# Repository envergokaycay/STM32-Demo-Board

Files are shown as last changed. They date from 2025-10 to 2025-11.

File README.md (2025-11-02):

# 🧠 STM32F417 Demo Board

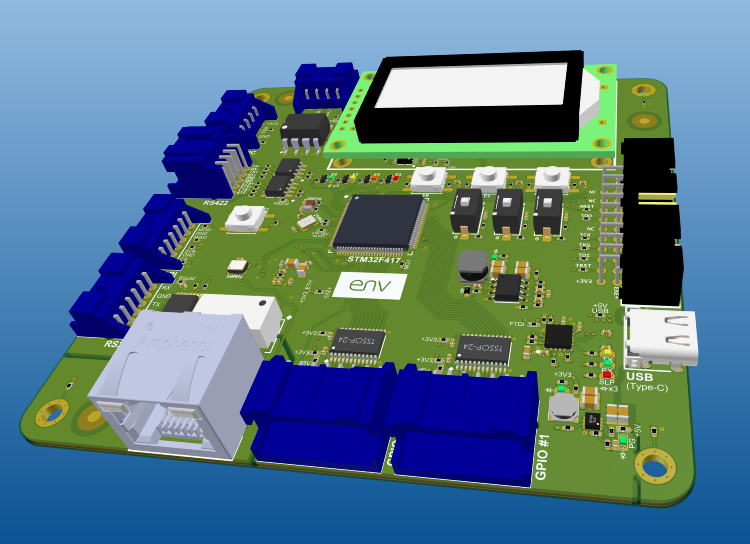
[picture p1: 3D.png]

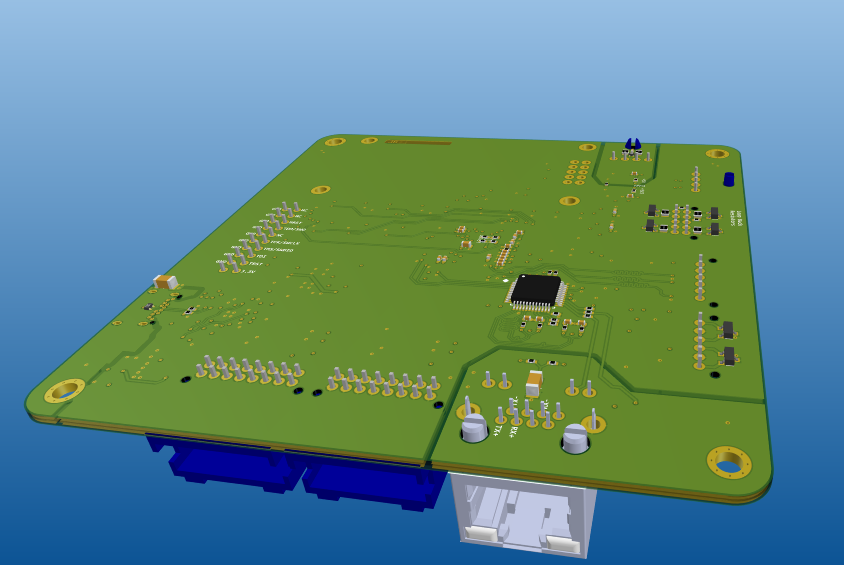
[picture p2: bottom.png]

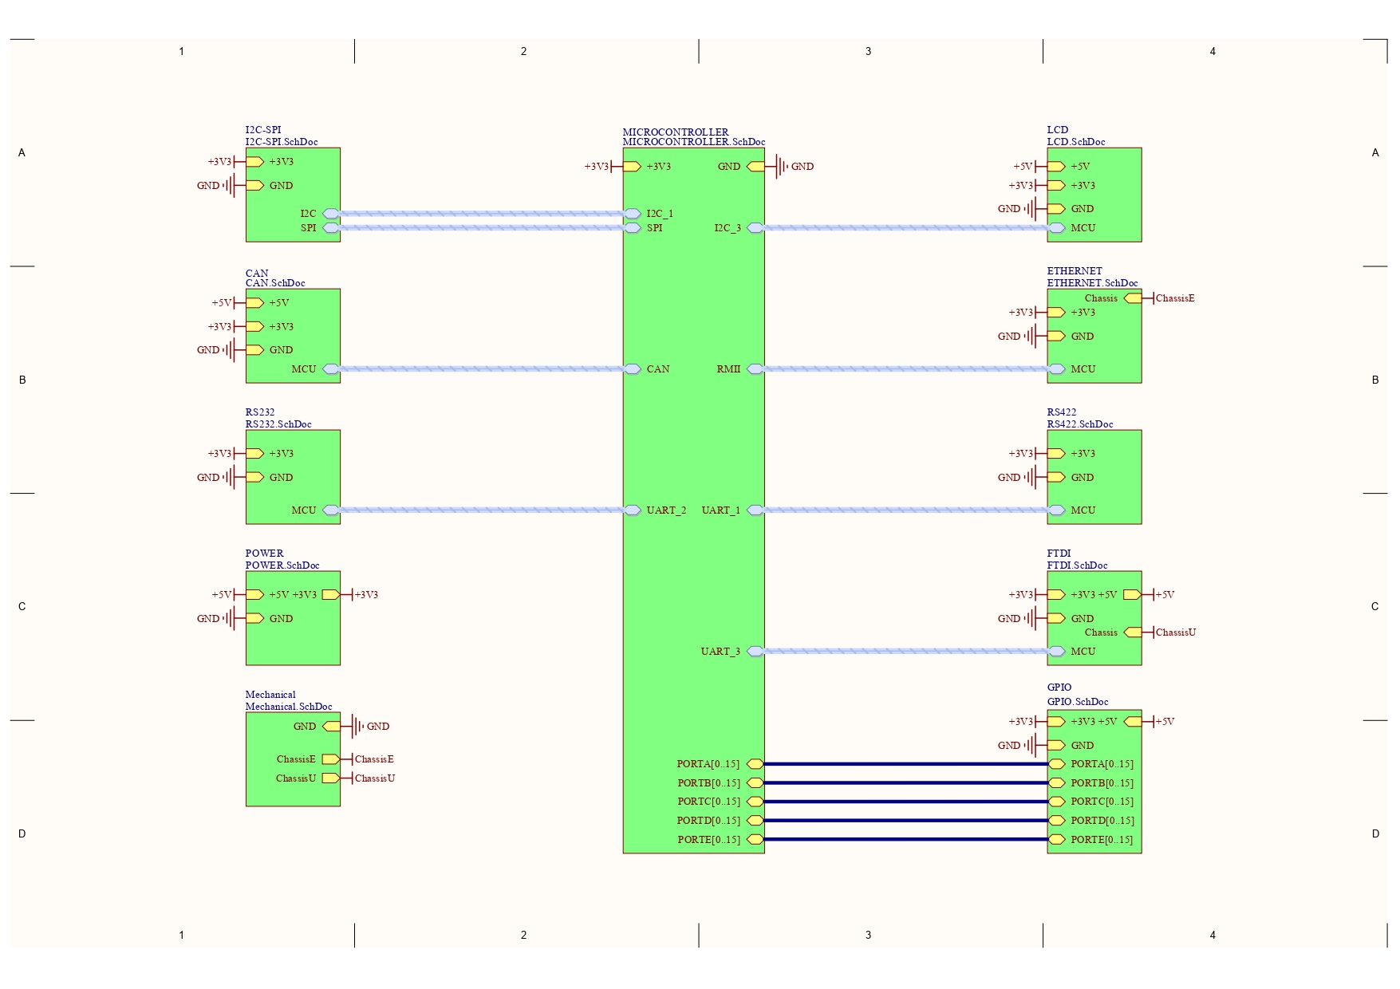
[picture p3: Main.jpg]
Main Board View


## 📘 Project Overview
This project presents a **multi-purpose demo board** developed for embedded system applications based on the **STM32F417VGT6** microcontroller.  
The design integrates communication, power management, and peripheral systems into a single modular platform suitable for both **educational** and **R&D** purposes.

---

## ⚙️ Technical Specifications

### 🔌 Power Management
- Input Voltage: **+5V / +3.3V regulation**
- Power Regulators: **AP3441SHE-7B, RT2862GSP**
- Power lines are monitorable via **LED indicators**

### 🧩 Microcontroller
- **STM32F417VGT6** (ARM Cortex-M4, 168 MHz, 1 MB Flash, 192 KB RAM)
- All **GPIO ports (A–E)** are accessible through pin headers.
- Includes **25 MHz external crystal oscillator** and **32.768 kHz RTC crystal**

### 🔄 Communication Interfaces
- **RS232** – Full UART conversion with TRS3232IPWR driver  
- **RS422** – Differential communication via SN65HVD30D transceiver  
- **CAN** – Industrial-level communication using ISO1050DUBR isolated driver  
- **USB-UART (FTDI)** – Implemented with FT230XQ-R chip for programming and serial communication  
- **Ethernet** – DP83848IVV/NOPB PHY over RMII protocol with RJ45 connector  

### 🖥️ Display Interface
- **I2C-based 8x2 LCD** (AMC0802BR)
- Level shifter: **NVT2002DP**
- Supports **backlight control** and **contrast adjustment**

### 🔬 Other Components
- **TVS diode protection** for all communication ports  
- **SWD/JTAG** programming interface  
- **Reset and Boot** push buttons  
- **GPIO expansion headers**

---

## 🧱 Hardware Files
The project was designed using **Altium Designer 23+**.  
It includes the following schematic files:

- `POWER.SchDoc` – Power circuit  
- `MICROCONTROLLER.SchDoc` – STM32F417 core  
- `CAN.SchDoc`, `RS232.SchDoc`, `RS422.SchDoc` – Communication modules  
- `FTDI.SchDoc` – USB–UART interface  
- `LCD.SchDoc` – Display module  
- `ETHERNET.SchDoc` – RMII Ethernet subsystem  
- `GPIO.SchDoc` – Pin mapping and expansion  
- `Mechanical.SchDoc` – Mechanical dimensions and references  

---

## 🧰 Development Environment
- **EDA Software:** Altium Designer 23.0  
- **Microcontroller IDE:** STM32CubeIDE  
- **Programming Interface:** ST-Link V2  
- **PCB Layers:** 4-layer  
- **Power Planes:** +3.3V / +5V / GND separated  

---

## 🚀 Use Cases
- Embedded system test platform  
- RS232/RS422/CAN communication experiments  
- Ethernet-based IoT or data transfer projects  
- LCD-based menu interface prototyping  
- Educational and hardware verification environments  

---

## 📁 Project Structure
```
📂 STM32F417_Demo_Board
 ├── Schematic_Files/
 │   ├── POWER.SchDoc
 │   ├── MICROCONTROLLER.SchDoc
 │   ├── RS232.SchDoc
 │   ├── RS422.SchDoc
 │   ├── CAN.SchDoc
 │   ├── LCD.SchDoc
 │   ├── FTDI.SchDoc
 │   ├── ETHERNET.SchDoc
 │   └── GPIO.SchDoc
 ├── PCB/
 │   └── STM32F417_Demo_Board.PcbDoc
 ├── Outputs/
 │   ├── Gerber/
 │   ├── Assembly/
 │   └── PDF/
 └── README.md
```

---

## 👨‍💻 Contact
If you have any questions or want to collaborate, feel free to reach out via GitHub or [LinkedIn](https://www.linkedin.com/in/envergokaycay/).

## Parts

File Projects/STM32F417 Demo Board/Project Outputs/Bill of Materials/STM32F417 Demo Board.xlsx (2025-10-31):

Description | Manufacturer | Manufacturer Part Number | Supplier Part Number | Supplier | Quantity | Supplier Currency | Supplier Link | Price, Min | Price, Max | Quantity, Min | Quantity, Max
 | KYOCERA AVX | 04026D104KAT4A | 478-11504-1-ND | Digikey | 47 | $ | https://www.digikey.com/en/products/detail/kyocera-avx/04026D104KAT4A/8107673 | $0.08000 | $0.00240 | 1 | 50,000
Cap, Cer, 22uF, 6.3V, M2012 | Murata | GRM21BR60J226ME39K | 490-6471-1-ND | Digikey | 8 | $ | https://www.digikey.com/en/products/detail/murata-electronics/GRM21BR60J226ME39K/2546881 | $0.21000 | $0.02815 | 1 | 30,000
Cap, Cer, 22pF, 25V, M1005 | Walsin | 0402N220J250CT | 1292-1282-1-ND | Digikey | 7 | $ | https://www.digikey.com/en/products/detail/walsin-technology-corporation/0402N220J250CT/9354779 | $0.10000 | $0.00128 | 1 | 250,000
Cap, Cer, 2.7nF, 50V, M1005 | Yageo | CC0402KRX7R9BB272 | 311-1033-1-ND | Digikey | 1 | $ | https://www.digikey.com/en/products/detail/yageo/CC0402KRX7R9BB272/302767 | $0.10000 | $0.00128 | 1 | 250,000
Cap, Cer, 1uF, 6.3V, M1005 | Samsung | CL10A475KQ8NNNC | 1276-1045-1-ND | Digikey | 2 | $ | https://www.digikey.com/en/products/detail/samsung-electro-mechanics/CL10A475KQ8NNNC/3886703 | $0.08000 | $0.00431 | 1 | 4,000
Cap, Cer, 1nF, 2kV, M3216 | Yageo | CC1206MKX7RDBB102 | 311-4501-1-ND | Digikey | 3 | $ | https://www.digikey.com/en/products/detail/yageo/CC1206MKX7RDBB102/5884663 | $0.23000 | $0.03901 | 1 | 75,000
Cap, Cer, 1uF, 6.3V, M1005 | Samsung | CL05A105MQ5NNNC | 1276-1235-1-ND | Digikey | 2 | $ | https://www.digikey.com/en/products/detail/samsung-electro-mechanics/CL05A105MQ5NNNC/3886893 | $0.10000 | $0.00211 | 1 | 250,000
Cap, Cer, 16pF, 50V, M1005 | Walsin | 0402N160J500CT | 1292-1262-1-ND | Digikey | 2 | $ | https://www.digikey.com/en/products/detail/walsin-technology-corporation/0402N160J500CT/9354759 | $0.10000 | $0.00182 | 1 | 250,000
Cap, Cer, 1uF, 6.3V, M1005 | Samsung | CL05A225MQ5NNNC | 1276-1469-1-ND | Digikey | 2 | $ | https://www.digikey.com/en/products/detail/samsung-electro-mechanics/CL05A225MQ5NNNC/3887127 | $0.08000 | $0.00241 | 1 | 10,000
Cap, Cer, 10uF, 6.3V, M2012 | Samsung | CL21A106MQFNNNE | 1292-1282-1-ND | Digikey | 2 | $ | https://www.digikey.com/en/products/detail/samsung-electro-mechanics/CL21A106MQFNNNE/3886956 | $0.10000 | $0.00846 | 1 | 50,000
Conn, JST, 4P, TH, XA, Side Entry | JST | S04B-XASK-1(LF)(SN) | 455-4090-ND | Digikey | 2 | $ | https://www.digikey.com/en/products/detail/jst-sales-america-inc/S04B-XASK-1-LF-SN/7230506 | $0.40000 | $0.21016 | 1 | 10,000
Connector, 6Pin | JST | S06B-PASK-2 | 455-S06B-PASK-2-ND | Digikey | 2 | $ | https://www.digikey.com/en/products/detail/jst-sales-america-inc/S06B-PASK-2/926757 | $0.38000 | $0.20057 | 1 | 10,000
Conn, JST, 16P, TH, PAD, Side Entry | JST | S16B-PADSS-1(LF)(SN) | 455-2037-ND | Digikey | 2 | $ | https://www.digikey.com/en/products/detail/jst-sales-america-inc/S16B-PADSS-1-LF-SN/1634778 | $0.62000 | $0.33258 | 1 | 10,080
Conn, JST, 10P, TH, PAD, Side Entry | JST | S10B-PADSS-1(LF)(SN) | 455-2032-ND | Digikey | 1 | $ | https://www.digikey.com/en/products/detail/jst-sales-america-inc/S10B-PADSS-1-LF-SN/1634773
Connector, USB, Type-C | GCT | USB4056-03-A | 2073-USB4056-03-ACT-ND | Digikey | 1 | $ | https://www.digikey.com/en/products/detail/gct/usb4056-03-a/14638038 | $0.91000 | $0.47490 | 1 | 10,000
Conn, Header, 20P, RA, TH, Shrouded | Omron | XG4C-2034 | OR900-ND | Digikey | 1 | $ | https://www.digikey.com/en/products/detail/omron-electronics-inc-emc-div/XG4C-2034/1787182 | 1.97 | 1.27716 | 1 | 450
RJ45 - Amphenol, RJHSE-x38-A1 | Amphenol | RJHSE-x38-A1 | RJHSE5381A1-ND | Digikey | 1 | $ | https://www.digikey.com/en/products/detail/amphenol-icc-commercial-products/rjhse5381a1/3083556 | $1.90000 | $1.09002 | 1 | 2,520
Diode, Schottky, 30V, 200mA, SOD-523 | Toshiba | CES521,L3F | CES521L3FCT-ND | Digikey | 1 | $ | https://www.digikey.com/en/products/detail/toshiba-semiconductor-and-storage/CES521-L3F/3522356 | $0.13000 | $0.01500 | 1 | 16,000
 | Rohm Semiconductor | SML-D12U1WT86 | SML-D12U1WT86CT-ND | Digikey | 11 | $ | https://www.digikey.com/en/products/detail/rohm-semiconductor/sml-d12u1wt86/5843853 | $0.12000 | $0.02318 | 1 | 300000
Diode, TVS, 5V/6.8V, SOD-723 | Toshiba | DF3A6.8LFV,L3F | DF3A6.8LFVL3FCT-ND | Digikey | 2 | $ | https://www.digikey.com/en/products/detail/toshiba-semiconductor-and-storage/DF3A6-8LFV-L3F/4305070 | $0.14000 | $0.02250 | 1 | 8,000
Housing, JST, 4P, XA | JST | XAP-04V-1 | 455-2150-ND | Digikey | 2 | $ | https://www.digikey.com/en/products/detail/jst-sales-america-inc/XAP-04V-1/959010 | $0.10000 | $0.05137 | 1 | 3,000
Housing, 6Pin | JST | PADP-16V-1-S | 455-2143-ND | Digikey | 2 | $ | https://www.digikey.com/en/products/detail/jst-sales-america-inc/PADP-16V-1-S/1300224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 | $0.26000 | $0.14985 | 1 | 3,000
Housing, 6Pin | JST | PADP-10V-1-S | 455-2140-ND | Digikey | 1 | $ | https://www.digikey.com/en/products/detail/jst-sales-america-inc/PADP-10V-1-S/1300221 | $0.13000 | $0.07648 | 1 | 3,000
Housing, 6Pin | JST | PAP-06V-S | 455-1490-ND | Digikey | 2 | $ | https://www.digikey.com/en/products/detail/jst-sales-america-inc/pap-06v-s/759978 | $0.13000 | $0.07648 | 1 | 3,000
IC, Power, DC-DC, Richtek, RT2862xSP | Richtek | RT2862GSP | 1028-1373-1-ND | Digikey | 1 | $ | https://www.digikey.com/en/products/detail/richtek-usa-inc/rt2862gsp/5880463 | $1.79000 | $0.87336 | 1 | 7,500
IC, Power, DC-DC, Diodes, AP3441 | Diodes | AP3441SHE-7B | AP3441SHE-7BDICT-ND | Digikey | 1 | $ | https://www.digikey.com/en/products/detail/diodes-incorporated/AP3441SHE-7B/9765636 | $0.31000 | $0.13728 | 1 | 1,000
IC, Buffer, Nexperia, TSSOP-24 | Nexperia | 74LVC4245APW,118 | 1727-4308-1-ND | Digikey | 2 | $ | https://www.digikey.com/en/products/detail/nexperia-usa-inc/74lvc4245apw-118/1231659 | $0.71000 | $0.34850 | 1 | 1,000
IC, Interface, CAN, DIP-8 | Texas Instruments | ISO1050DUBR | 296-24818-1-ND | Digikey | 1 | $ | https://www.digikey.com/en/products/detail/texas-instruments/iso1050dubr/2094633 | $3.72000 | $2.32380 | 1 | 100
IC, Interface, RS232, Texas | Texas Instruments | TRS3232IPWR | 296-25041-1-ND | Digikey | 1 | $ | https://www.digikey.com/en/products/detail/texas-instruments/trs3232ipwr/1909117 | $1.73000 | $0.90061 | 1 | 1,000
IC, Interface, RS422, Texas | Texas Instruments | SN65HVD30D | 296-26346-5-ND | Digikey | 2 | $ | https://www.digikey.com/en/products/detail/texas-instruments/sn65hvd30d/1574539
IC, Interface, I2C, TSSOP-8 | Nexperia | NVT2002DP,118 | 568-5121-1-ND | Digikey | 1 | $ | https://www.digikey.com/en/products/detail/nxp-usa-inc/NVT2002DP-118/2355938 | $0.62000 | $0.25914 | 1 | 25,000
Module, LCD, Orient, AMC0802BR-B-B6WTDW-SPI | Orient Display | AMC0802BR-B-B6WTDW-I2C | 5491-AMC0802BR-B-B6WTDW-I2C-ND | Digikey | 1 | $ | https://www.digikey.com/en/products/detail/orient-display/amc0802br-b-b6wtdw-i2c/22531884 | $10.32000 | $5.74189 | 1 | 1,000
IC, Interface, FTDI, QFN-16 | FTDI | FT230XQ-R | 768-1130-1-ND | Digikey | 1 | $ | https://www.digikey.com/en/products/detail/ftdi-future-technology-devices-international-ltd/FT230XQ-R/3029142 | $2.26000 | $1.63030 | 1 | 5,000
IC, MCU, STM32F417VxTx, QFP-100 | STM | STM32F417VGT6 | 497-11900-ND | Digikey | 1 | $ | https://www.digikey.com/en/products/detail/stmicroelectronics/stm32f417vgt6/2757684 | $12.09000 | $7.40087 | 1 | 1080
IC, Interface, Eth Phy, 10/100Mb, DP83848IVV | Texas | DP83848IVV/NOPB | DP83848IVV/NOPB-ND | Digikey | 1 | $ | https://www.digikey.com/en/products/detail/texas-instruments/DP83848IVV-NOPB/947543 | $6.93000 | $3.95780 | 1 | 2,500
IC, Oscillator, 50 MHz | ESC | ECS-2333-500-BN-TR | XC1930CT-ND | Digikey | 1 | $ | https://www.digikey.com/en/products/detail/ecs-inc/ecs-2333-500-bn-tr/3927356 | $0.90000 | $0.61814 | 1 | 500
Inductor | Taiyo Yuden | NRS5020T4R7MMGJ | 587-2890-1-ND | Digikey | 1 | $ | https://www.digikey.com/en/products/detail/taiyo-yuden/NRS5020T4R7MMGJ/2230192 | $0.18000 | $0.07087 | 1 | 87,750
Inductor | Taiyo Yuden | NRS4018T2R2MDGJ | 587-2890-1-ND | Digikey | 1 | $ | https://www.digikey.com/en/products/detail/taiyo-yuden/nrs4018t2r2mdgj/2648968 | $0.18000 | $0.07087 | 1 | 87,750
Logo |  |  |  |  | 1
Pin, JST, SXA-001T-P0.6 | JST | SXA-001T-P0.6 | 455-1904-1-ND | Digikey | 8 | $ | https://www.digikey.com/en/products/detail/jst-sales-america-inc/SXA-001T-P0-6/923775 | $0.01620 | $0.01171 | 8,000 | 800,000
Pin | JST | SPND-001T-C0.5 | 455-2303-1-ND | Digikey | 42 | $ | https://www.digikey.com/en/products/detail/jst-sales-america-inc/SPND-001T-C0-5/1788519 | $0.02410 | $* | 1,000
Pin | JST | SPHD-001T-P0.5 | 455-1325-1000-ND | Digikey | 12 | $ | https://www.digikey.com/en/products/detail/jst-sales-america-inc/sphd-001t-p0-5/26212452 | $0.02410 | $* | 1,000
MOSFET, N-CH, 20V, 100mA, SOT-416FL | Rohm | RE1C001UNTCL | RE1C001UNTCLCT-ND | Digikey | 4 | $ | https://www.digikey.com/en/products/detail/rohm-semiconductor/RE1C001UNTCL/4004557 | $0.30000 | $0.03713 | 1 | 15,000
Res, 1K, 1%, M1005 | Yageo | RC0402FR-071KP | YAG1254CT-ND | Digikey | 10 | $ | https://www.digikey.com/en/products/detail/yageo/RC0402FR-071KP/4935269 | $0.10000 | $0.00306 | 1 | 10,000
Res, 100K, 1%, M1005 | Yageo | RC0402FR-07100KP | 13-RC0402FR-07100KPCT-ND | Digikey | 11 | $ | https://www.digikey.com/en/products/detail/yageo/RC0402FR-07100KP/12698883 | $0.12000 | $0.00306 | 1 | 10,000
Res, 330R, 1%, M1005 | Yageo | RC0402FR-07330RL | 311-330LRCT-ND | Digikey | 20 | $ | https://www.digikey.com/en/products/detail/yageo/RC0402FR-07330RL/726594 | $0.10000 | $0.00181 | 1 | 250,000
 | Yageo | RC0402FR-070RL | 311-0.0LRCT-ND | Digikey | 39 | $ | https://www.digikey.com/en/products/detail/yageo/RC0402FR-070RL/2827570 | $0.10000 | $0.00133 | 1 | 250000
Res, 150K, 1%, M1005 | Yageo | RC0402FR-07150KL | 311-150KLRCT-ND | Digikey | 1 | $ | https://www.digikey.com/en/products/detail/yageo/RC0402FR-07150KL/726542 | $0.11000 | $0.00181 | 1 | 250,000
Res, 75K, 1%, M1005 | Yageo | RC0402FR-0775KL | 311-75KLRCT-ND | Digikey | 1 | $ | https://www.digikey.com/en/products/detail/yageo/RC0402FR-0775KL/2827576 | $0.10000 | $0.00181 | 1 | 250,000
Res, 24K, 1%, M1005 | Yageo | RC0402FR-0724KL | 311-24KLRCT-ND | Digikey | 1 | $ | https://www.digikey.com/en/products/detail/yageo/RC0402FR-0724KL/2827581 | $0.10000 | $0.00153 | 1 | 20,000
Res, 56K, 1%, M1005 | Yageo | RC0402FR-0756KL | 311-56.0KLRCT-ND | Digikey | 2 | $ | https://www.digikey.com/en/products/detail/yageo/RC0402FR-0756KL/726635 | $0.10000 | $0.00181 | 1 | 250,000
Res, 16K, 1%, M1005 | Yageo | RC0402FR-0716KL | 311-16.0KLRCT-ND | Digikey | 1 | $ | https://www.digikey.com/en/products/detail/yageo/RC0402FR-0716KL/726544 | $0.10000 | $0.00127 | 1 | 10,000
Res, 453K, 1%, M1005 | Yageo | RC0402FR-07453KL | YAG3164CT-ND | Digikey | 1 | $ | https://www.digikey.com/en/products/detail/yageo/RC0402FR-07453KL/5281024 | $0.10000 | $0.00127 | 1 | 10,000
Res, 2.2K, 1%, M1005 | Yageo | RC0402FR-072K2L | 311-2.20KLRCT-ND | Digikey | 6 | $ | https://www.digikey.com/en/products/detail/yageo/RC0402FR-072K2L/726553 | $0.10000 | $0.00181 | 1 | 70,000
Res, 60.4R, 1%, M2012 | Yageo | RC0805FR-0760R4L | 311-60.4CRCT-ND | Digikey | 6 | $ | https://www.digikey.com/en/products/detail/yageo/RC0805FR-0760R4L/728073 | $0.10000 | $0.00357 | 1 | 10,000
Res, 10K, 1%, M1005 | Yageo | RC0402FR-0710KP | YAG1249CT-ND | Digikey | 11 | $ | https://www.digikey.com/en/products/detail/yageo/RC0402FR-0710KP/4935264 | $0.11000 | $0.00359 | 1 | 250,000
Res, 22R, 1%, M1005 | Yageo | RC0402FR-0722RL | 311-22.0LRCT-ND | Digikey | 16 | $ | https://www.digikey.com/en/products/detail/yageo/RC0402FR-0722RL/726562 | $0.10000 | $0.00181 | 1 | 70,000
Res, 200K, 1%, M1005 | Yageo | RC0402FR-07200KL | 311-200KLRCT-ND | Digikey | 1 | $ | https://www.digikey.com/en/products/detail/yageo/RC0402FR-07200KL/726558
Res, 4.7K, 1%, M1005 | Yageo | RC0402FR-074K7L | 311-4.7KLRCT-ND | Digikey | 5 | $ | https://www.digikey.com/en/products/detail/yageo/RC0402FR-074K7L/2827563 | $0.10000 | $0.00204 | 1 | 10,000
Res, 4.87K, 1%, M1005 | Yageo | RC0402FR-074K87L | YAG3175CT-ND | Digikey | 1 | $ | https://www.digikey.com/en/products/detail/yageo/RC0402FR-074K87L/5281035 | $0.10000 | $0.00181 | 1 | 70,000
Res, 51R, 1%, M1005 | Yageo | RC0402FR-0751RL | 311-51.0LRCT-ND | Digikey | 4 | $ | https://www.digikey.com/en/products/detail/yageo/RC0402FR-0751RL/726629 | $0.10000 | $0.00181 | 1 | 70,000
Res, 75R, 1%, M1005 | Yageo | RC0402FR-0775RL | 311-75.0LRCT-ND | Digikey | 2 | $ | https://www.digikey.com/en/products/detail/yageo/RC0402FR-0775RL/726658 | $0.12000 | $0.00306 | 1 | 10,000
Switch, Slide, SPST, SMD | C&K | SDA01H1SBD | CKN10358-ND | Digikey | 3 | $ | https://www.digikey.com/en/products/detail/c-k/SDA01H1SBD/2263273 | $1.71000 | $0.92375 | 1 | 5,000
Switch, Tactile, SPST, SMD | Panasonic | EVQ-Q2K03W | P12943SCT-ND | Digikey | 4 | $ | https://www.digikey.com/en/products/detail/panasonic-electronic-components/EVQ-Q2K03W/762893 | $0.29000 | $0.13296 | 1 | 50,000
Transformer, Eth, 100Mbps, SM13126PEL | Bourns | SM13126PEL | SM13126PELCT-ND | Digikey | 1 | $ | https://www.digikey.com/en/products/detail/bourns-inc/SM13126PEL/10229989
TVS, 2P, Bidirectional, 7V/12V, SOT-23-3 | Bourns | CDSOT23-SM712 | CDSOT23-SM712CT-ND | Digikey | 6 | $ | https://www.digikey.com/en/products/detail/bourns-inc/CDSOT23-SM712/1630592 | $ | $0.25000 | 1 | 15,000
XTAL, 32.768kHz, 12.5pF | NDK | NX3215SA-32.768K-STD-MUS-2 | 644-1159-1-ND | Digikey | 1 | $ | https://www.digikey.com/en/products/detail/ndk-america-inc/NX3215SA-32-768K-STD-MUS-2/2349033 | $0.63000 | $0.34424 | 1 | 21,000
XTAL, 25MHz, 12pF | Kyocera | CX3225SB25000H0FLJCC | 478-CX3225SB25000H0FLJCCCT-ND | Digikey | 1 | $ | https://www.digikey.com/en/products/detail/kyocera-avx/cx3225sb25000h0fljcc/6123312 | $0.66000 | $0.36682 | 1 | 21,000
